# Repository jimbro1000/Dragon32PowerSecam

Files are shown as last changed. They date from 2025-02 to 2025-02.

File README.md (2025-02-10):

# SECAM Dragon 32 Power Board

This project is a historic record of the Dragon 32 SECAM power board.
Part Number 41504. This is not intended for fabrication but should be
dimensionally correct.

The board is unique in that it contains a full YPrPb conversion to
RGB - something very lacking from the original design

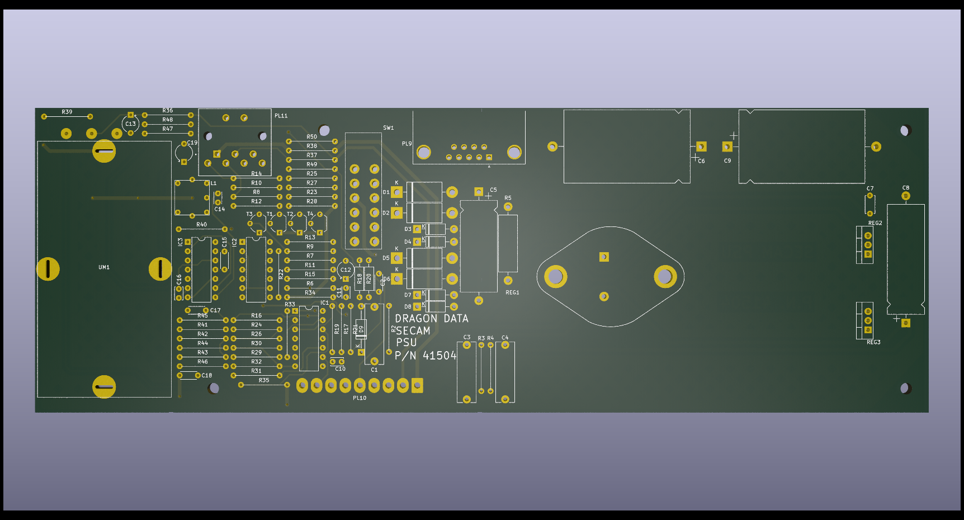
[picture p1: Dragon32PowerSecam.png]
Render of pcb top


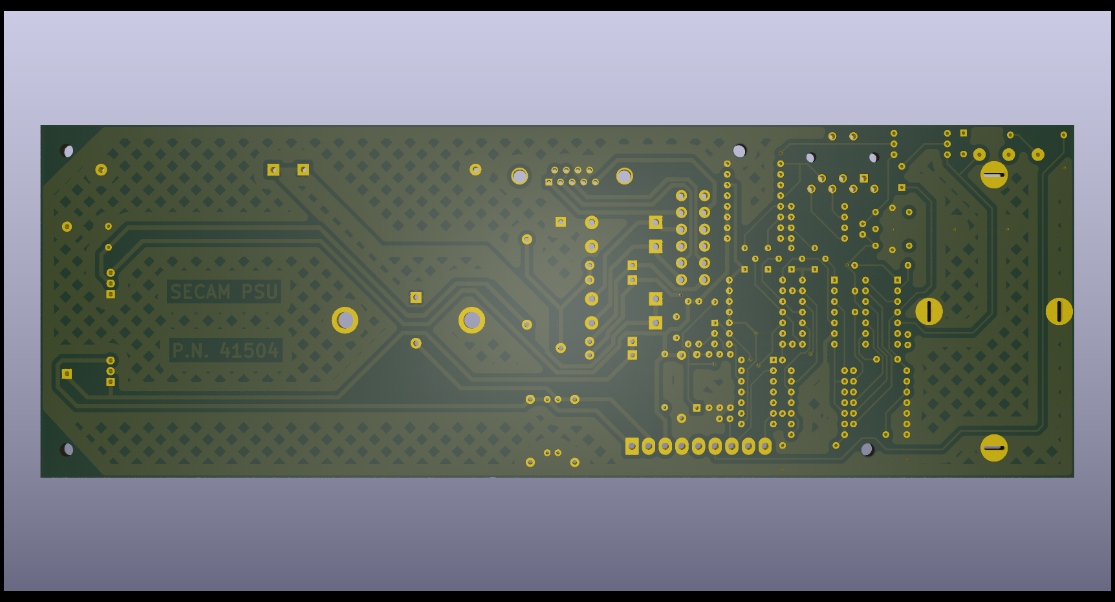
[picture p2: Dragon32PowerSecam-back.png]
Render of pcb bottom


## Compatibility

This board can only be used with a SECAM version of the main CPU
board, see https://github.com/jimbro1000/Dragon32Issue2aSecam

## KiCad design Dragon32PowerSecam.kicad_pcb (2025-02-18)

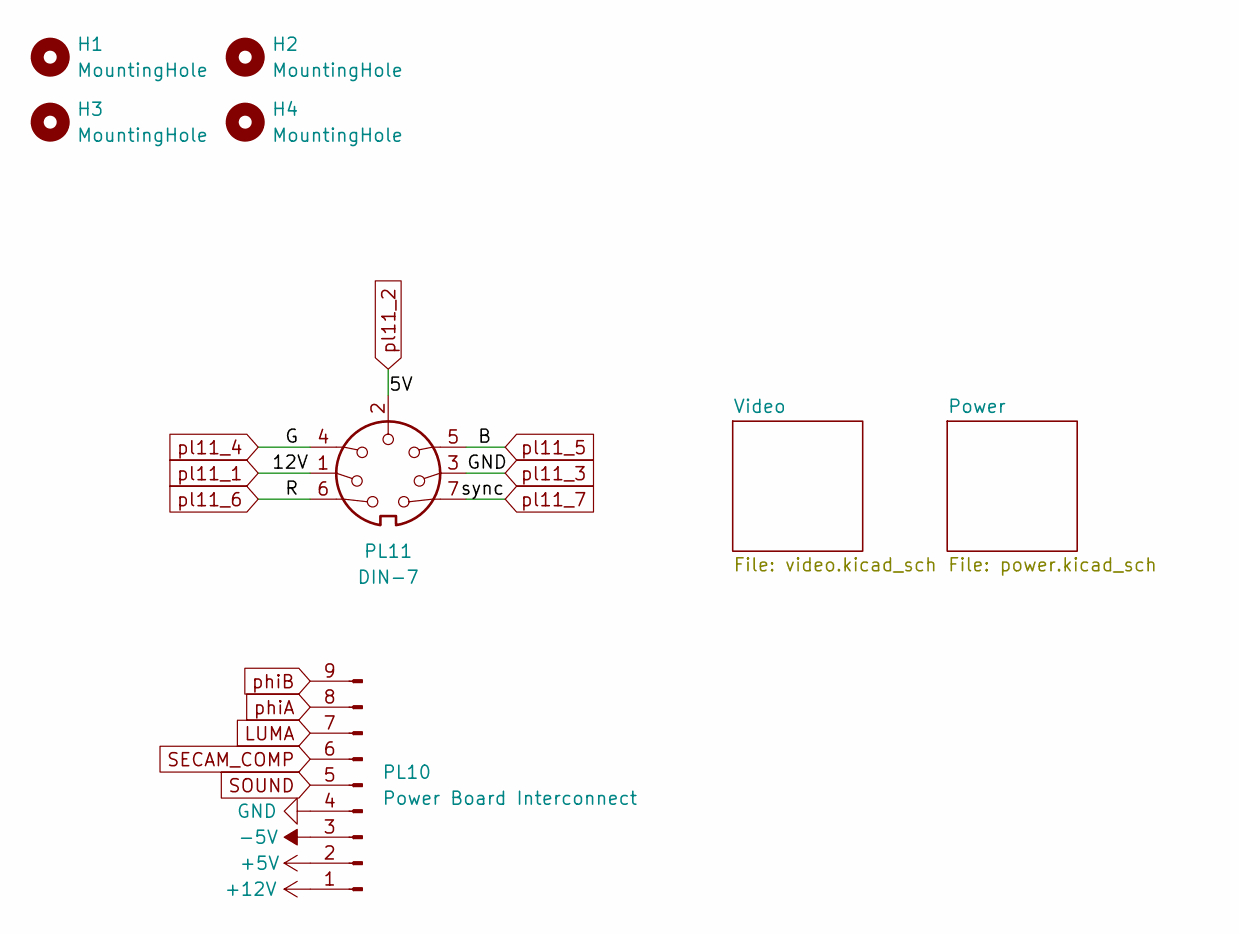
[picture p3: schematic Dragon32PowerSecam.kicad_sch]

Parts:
H1, H2, H3, H4: MountingHole; MountingHole_3.2mm_M3
PL10: Power Board Interconnect; Molex_KK-396_A-41791-0009_1x09_P3.96mm_Vertical; DigiKey 2057-LHD-09-TS-ND
PL11: DIN-7; CUI_SDS-70J; DigiKey CP-2370-ND

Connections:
+5V: PL10.2; also elsewhere on the board
+12V: PL10.1; also elsewhere on the board
-5V: PL10.3; also elsewhere on the board
LUMA: PL10.7; also elsewhere on the board
SECAM_COMP: PL10.6; also elsewhere on the board
SOUND: PL10.5; also elsewhere on the board
phiA: PL10.8; also elsewhere on the board
phiB: PL10.9; also elsewhere on the board
pl11_1: PL11.1; also elsewhere on the board
pl11_2: PL11.2; also elsewhere on the board
pl11_3: PL10.4, PL11.3; also elsewhere on the board
pl11_4: PL11.4; also elsewhere on the board
pl11_5: PL11.5; also elsewhere on the board
pl11_6: PL11.6; also elsewhere on the board
pl11_7: PL11.7; also elsewhere on the board

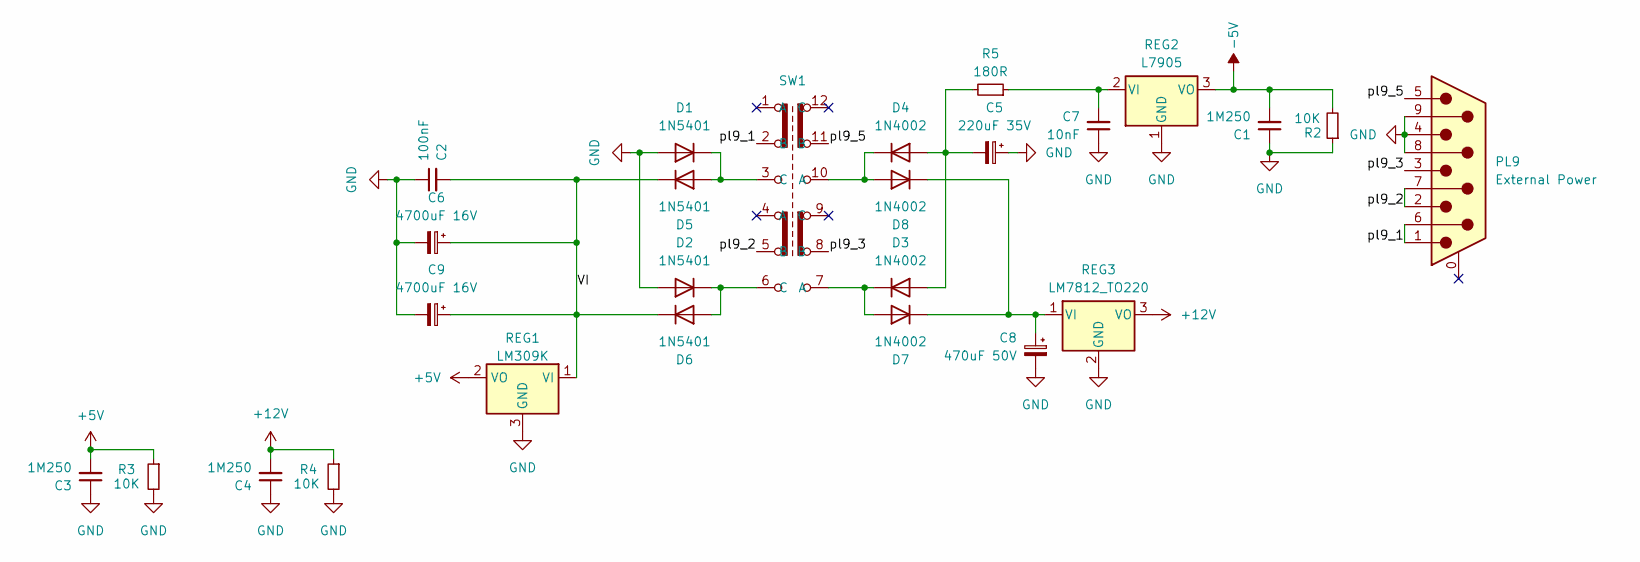
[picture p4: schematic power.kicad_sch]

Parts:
C1, C3, C4: 1M250; C_Rect_L16.5mm_W5.0mm_P15.00mm_MKT
C2: 100nF; C_Disc_D4.3mm_W1.9mm_P5.00mm
C5: 220uF 35V; CP_Axial_L25.0mm_D10.0mm_P30.00mm_Horizontal
C6, C9: 4700uF 16V; CP_Axial_L34.5mm_D20.0mm_P41.00mm_Horizontal
C7: 10nF; C_Disc_D4.7mm_W2.5mm_P5.00mm
C8: 470uF 50V; CP_Axial_L30.0mm_D10.0mm_P35.00mm_Horizontal
D1, D2, D5, D6: 1N5401; D_DO-201AD_P15.24mm_Horizontal
D3, D4, D7, D8: 1N4002; D_DO-41_SOD81_P10.16mm_Horizontal
PL9: External Power; DSUB-9_Male_Horizontal_P2.77x2.84mm_EdgePinOffset9.90mm_Hou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
R2, R3, R4: 10K; R_Axial_DIN0309_L9.0mm_D2.5mm_P12.70mm_Horizontal
R5: 180R; R_Axial_DIN0516_L15.5mm_D5.0mm_P20.32mm_Horizontal
REG1: LM309K; TO-3
REG2: L7905; TO-220-3_Vertical
REG3: LM7812_TO220; TO-220-3_Vertical
SW1: Switch_Push_Interlock_4P2T

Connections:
+5V: C3.2, R3.1, REG1.2 (VO); also elsewhere on the board
+12V: C4.2, R4.1, REG3.3 (VO); also elsewhere on the board
-5V: C1.2, R2.2, REG2.3 (VO); also elsewhere on the board
/Power/VI: C2.2, C6.1, C9.1, D5.1 (K), D6.1 (K), REG1.1 (VI)
/Power/pl9_1: PL9.1, PL9.6, SW1.2 (B)
/Power/pl9_2: PL9.2, PL9.7, SW1.5 (B)
/Power/pl9_3: PL9.3, SW1.8 (B)
/Power/pl9_5: PL9.5, SW1.11 (B)
unnamed: D1.1 (K), D5.2 (A), SW1.3 (C)
unnamed: D2.1 (K), D6.2 (A), SW1.6 (C)
unnamed: C5.2, D3.2 (A), D4.2 (A), R5.2
unnamed: D3.1 (K), D7.2 (A), SW1.7 (A)
unnamed: D4.1 (K), D8.2 (A), SW1.10 (A)
unnamed: C8.1, D7.1 (K), D8.1 (K), REG3.1 (VI)
unnamed: C7.2, R5.1, REG2.2 (VI)
pl11_3: C1.1, C2.1, C3.1, C4.1, C5.1, C6.2, C7.1, C8.2, C9.2, D1.2 (A), D2.2 (A), PL9.4, PL9.8, PL9.9, R2.1, R3.2, R4.2, REG1.3 (GND), REG2.1 (GND), REG3.2 (GND); also elsewhere on the board

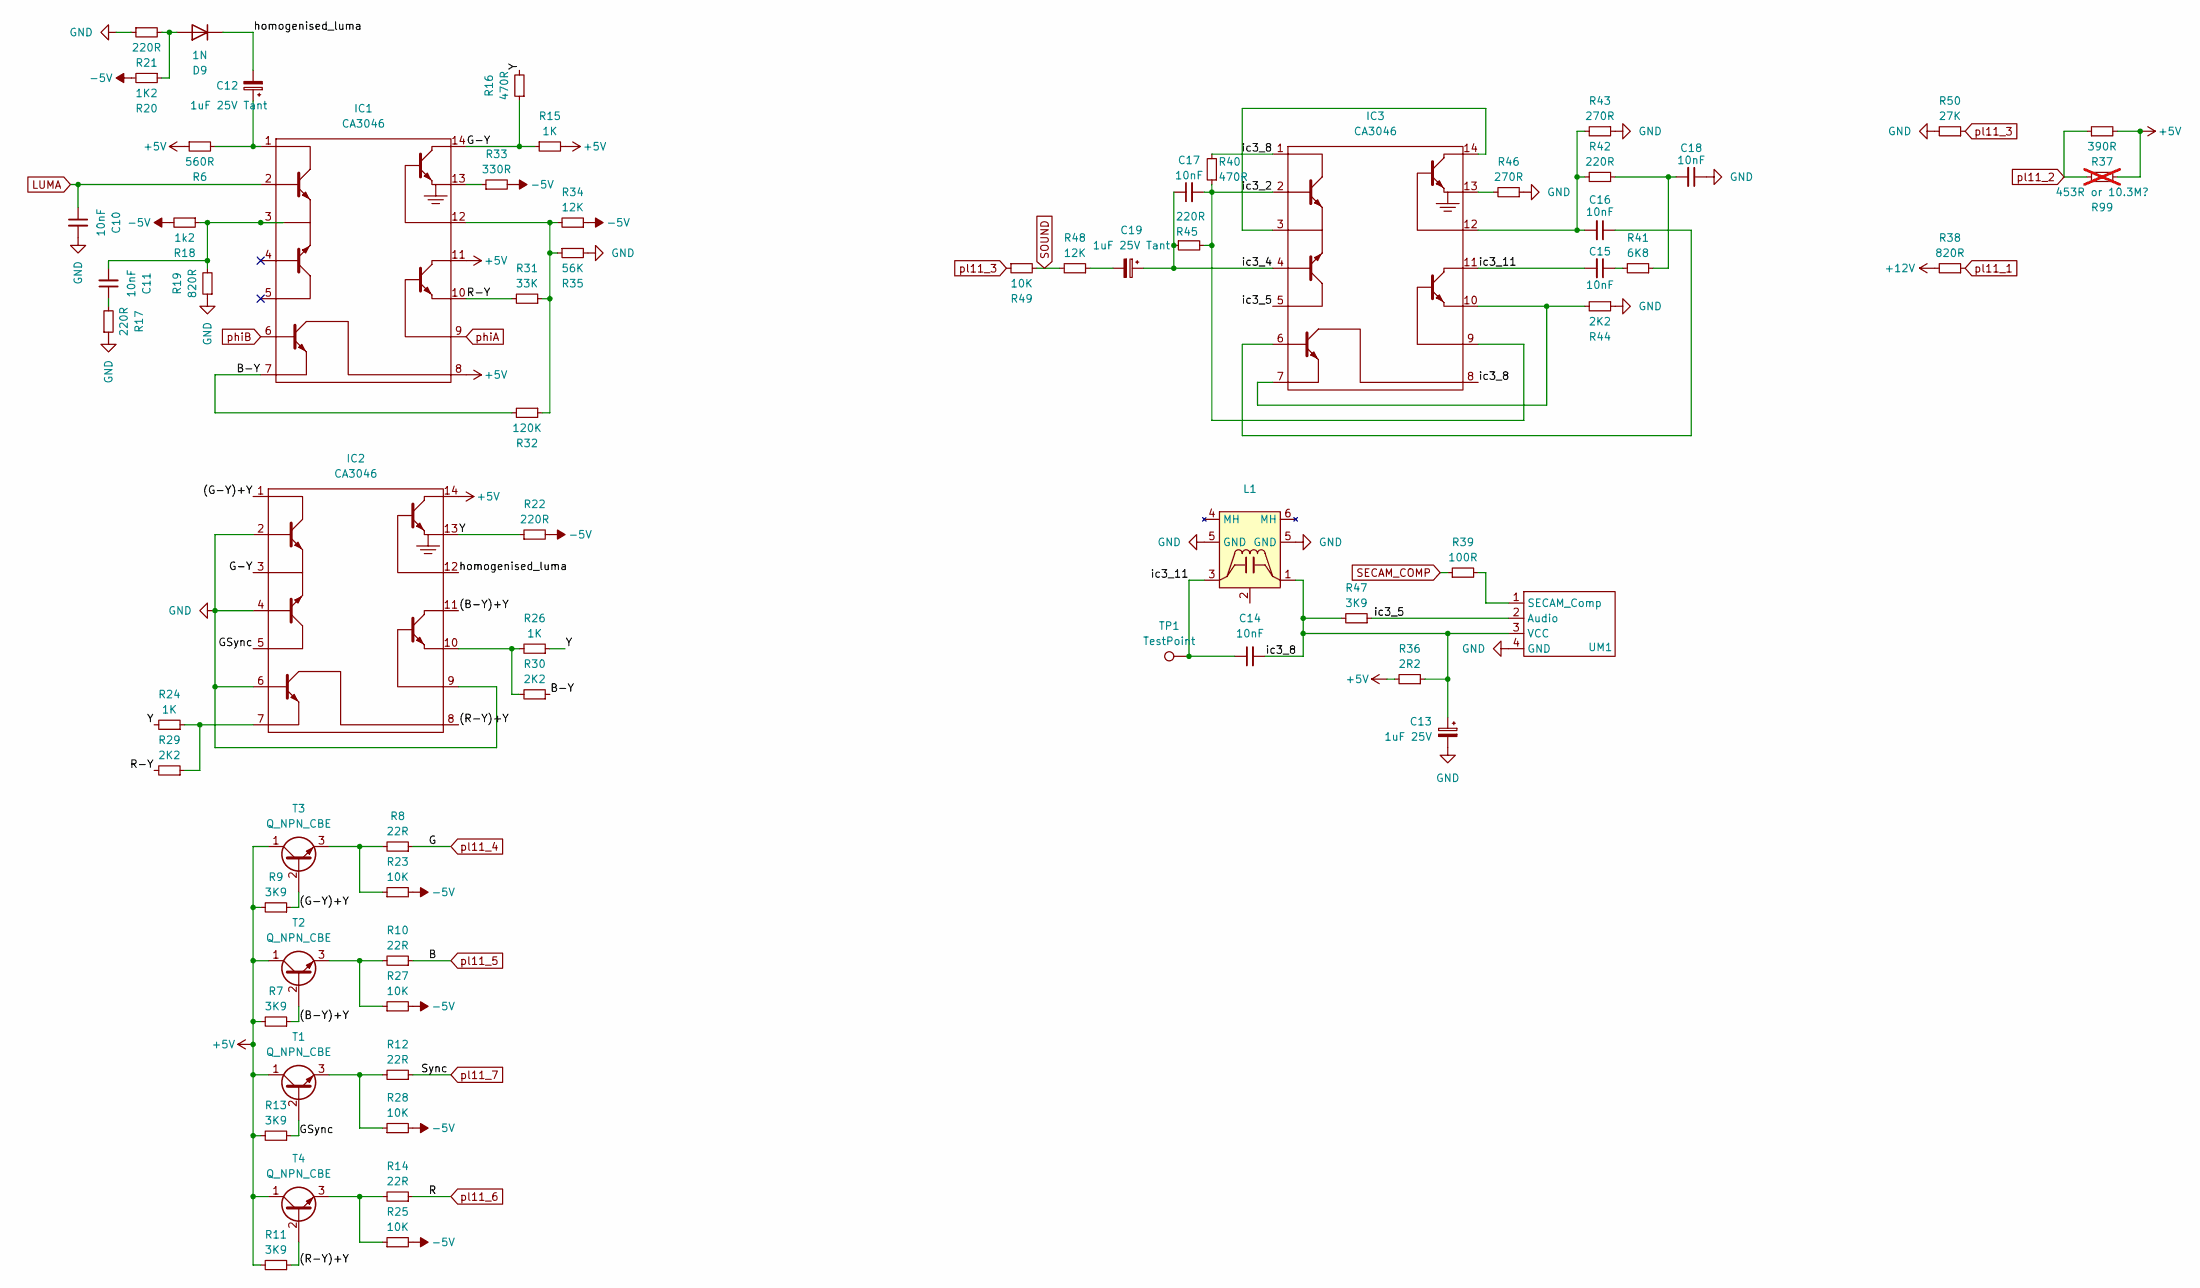
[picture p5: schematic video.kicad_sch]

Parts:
C10, C16: 10nF; C_Disc_D3.4mm_W2.1mm_P2.50mm
C11, C14: 10nF; C_Disc_D3.0mm_W2.0mm_P2.50mm
C12, C19: 1uF 25V Tant; CP_Radial_Tantal_D4.5mm_P5.00mm
C13: 1uF 25V; CP_Radial_Tantal_D4.5mm_P5.00mm
C15, C17, C18: 10nF; C_Disc_D4.3mm_W1.9mm_P5.00mm
D9: 1N; D_A-405_P12.70mm_Horizontal
IC1, IC2, IC3: CA3046; DIP-14_W7.62mm
L1: TOKO_RCL_10K
R6: 560R; R_Axial_DIN0309_L9.0mm_D2.5mm_P12.70mm_Horizontal
R7, R9, R11, R13, R47: 3K9; R_Axial_DIN0309_L9.0mm_D2.5mm_P12.70mm_Horizontal
R8, R10, R12, R14: 22R; R_Axial_DIN0309_L9.0mm_D2.5mm_P12.70mm_Horizontal
R15, R24, R26: 1K; R_Axial_DIN0309_L9.0mm_D2.5mm_P12.70mm_Horizontal
R16, R40: 470R; R_Axial_DIN0309_L9.0mm_D2.5mm_P12.70mm_Horizontal
R17, R21, R22, R42, R45: 220R; R_Axial_DIN0309_L9.0mm_D2.5mm_P12.70mm_Horizontal
R18: 1k2; R_Axial_DIN0207_L6.3mm_D2.5mm_P10.16mm_Horizontal
R19, R38: 820R; R_Axial_DIN0309_L9.0mm_D2.5mm_P12.70mm_Horizontal
R20: 1K2; R_Axial_DIN0207_L6.3mm_D2.5mm_P10.16mm_Horizontal
R23, R25, R27, R28, R49: 10K; R_Axial_DIN0309_L9.0mm_D2.5mm_P12.70mm_Horizontal
R29, R30, R44: 2K2; R_Axial_DIN0309_L9.0mm_D2.5mm_P12.70mm_Horizontal
R31: 33K; R_Axial_DIN0309_L9.0mm_D2.5mm_P12.70mm_Horizontal
R32: 120K; R_Axial_DIN0309_L9.0mm_D2.5mm_P12.70mm_Horizontal
R33: 330R; R_Axial_DIN0309_L9.0mm_D2.5mm_P12.70mm_Horizontal
R34, R48: 12K; R_Axial_DIN0309_L9.0mm_D2.5mm_P12.70mm_Horizontal
R35: 56K; R_Axial_DIN0309_L9.0mm_D2.5mm_P12.70mm_Horizontal
R36: 2R2; R_Axial_DIN0309_L9.0mm_D2.5mm_P12.70mm_Horizontal
R37: 390R; R_Axial_DIN0309_L9.0mm_D2.5mm_P12.70mm_Horizontal
R39: 100R; R_Axial_DIN0309_L9.0mm_D2.5mm_P12.70mm_Horizontal
R41: 6K8; R_Axial_DIN0309_L9.0mm_D2.5mm_P12.70mm_Horizontal
R43, R46: 270R; R_Axial_DIN0309_L9.0mm_D2.5mm_P12.70mm_Horizontal
R50: 27K; R_Axial_DIN0309_L9.0mm_D2.5mm_P12.70mm_Horizontal
R99: 453R or 10.3M?; R_Axial_DIN0309_L9.0mm_D2.5mm_P12.70mm_Horizontal; not fitted
T1, T2, T3, T4: Q_NPN_CBE; TO-92_Wide
TP1: TestPoint; TestPoint_THTPad_D1.0mm_Drill0.5mm
UM1: RF_Modulator_Astec_UM1601

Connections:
+5V: IC1.8, IC1.11, IC2.14, R6.1, R7.2, R9.2, R11.2, R13.2, R15.2, R36.2, R37.2, R99.2, T1.1 (C), T2.1 (C), T3.1 (C), T4.1 (C); also elsewhere on the board
+12V: R38.2; also elsewhere on the board
-5V: R18.2, R20.2, R22.2, R23.2, R25.2, R27.2, R28.2, R33.2, R34.1; also elsewhere on the board
/Video/(B-Y)+Y: IC2.11, R7.1, T2.2 (B)
/Video/(G-Y)+Y: IC2.1, R9.1, T3.2 (B)
/Video/(R-Y)+Y: IC2.8, R11.1, T4.2 (B)
/Video/B-Y: IC1.7, R30.1, R32.2
/Video/G-Y: IC1.14, IC2.3, R15.1, R16.1
/Video/GSync: IC2.5, R13.1, T1.2 (B)
/Video/R-Y: IC1.10, R29.2, R31.2
/Video/Y: IC2.13, R16.2, R22.1, R24.2, R26.1
/Video/homogenised_luma: C12.2, D9.1 (K), IC2.12
/Video/ic3_2: C17.2, IC3.2, IC3.9, R40.1, R45.2
/Video/ic3_4: C17.1, C19.1, IC3.4, R45.1
/Video/ic3_5: IC3.5, R47.1, UM1.2 (Audio)
/Video/ic3_8: C13.1, C14.2, IC3.1, IC3.8, L1.1, R36.1, R40.2, R47.2, UM1.3 (VCC)
/Video/ic3_11: C14.1, C15.2, IC3.11, L1.3, TP1.1
LUMA: C10.1, IC1.2; also elsewhere on the board
unnamed: C11.1, R17.2
unnamed: C11.2, IC1.3, R18.1, R19.2
unnamed: C12.1, IC1.1, R6.2
unnamed: C15.1, R41.2
unnamed: C16.1, IC3.6
unnamed: C16.2, IC3.12, R42.2, R43.2
unnamed: C18.2, R41.1, R42.1
unnamed: C19.2, R48.1
unnamed: D9.2 (A), R20.1, R21.2
unnamed: IC1.12, R31.1, R32.1, R34.2, R35.1
unnamed: IC1.13, R33.1
unnamed: IC2.7, R24.1, R29.1
unnamed: IC2.10, R26.2, R30.2
unnamed: IC3.7, IC3.10, R44.2
unnamed: IC3.13, R46.2
unnamed: IC3.3, IC3.14
unnamed: R12.2, R28.1, T1.3 (E)
unnamed: R10.2, R27.1, T2.3 (E)
unnamed: R8.2, R23.1, T3.3 (E)
unnamed: R14.2, R25.1, T4.3 (E)
unnamed: R39.2, UM1.1 (SECAM_Comp)
SECAM_COMP: R39.1; also elsewhere on the board
SOUND: R48.2, R49.2; also elsewhere on the board
phiA: IC1.9; also elsewhere on the board
phiB: IC1.6; also elsewhere on the board
pl11_1: R38.1; also elsewhere on the board
pl11_2: R37.1, R99.1; also elsewhere on the board
pl11_3: C10.2, C13.2, C18.1, IC2.2, IC2.4, IC2.6, IC2.9, L1.5 (GND), R17.1, R19.1, R21.1, R35.2, R43.1, R44.1, R46.1, R49.1, R50.1, R50.2, UM1.4 (GND); also elsewhere on the board
pl11_4: R8.1; also elsewhere on the board
pl11_5: R10.1; also elsewhere on the board
pl11_6: R14.1; also elsewhere on the board
pl11_7: R12.1; also elsewhere on the board

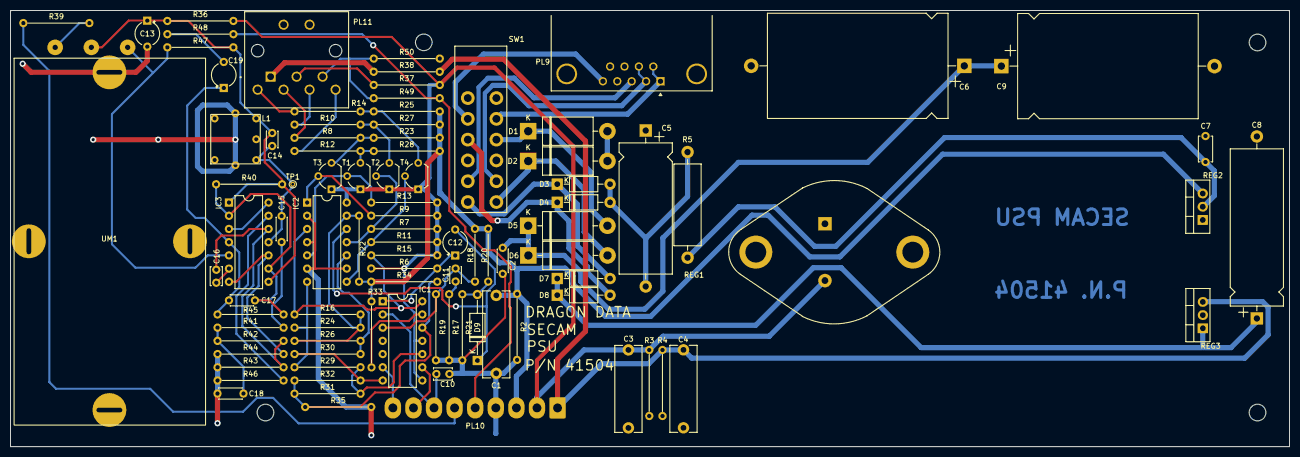
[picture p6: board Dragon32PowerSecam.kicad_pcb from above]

Board: 2 copper layers, 246.0 x 83.9 mm, 98 parts (0 on the bottom side), 62 nets.

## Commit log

2025-02-04 initial layout
    [Dragon32PowerSecam.kicad_pcb, Dragon32PowerSecam.kicad_sch, power.kicad_sch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]
2025-02-04 video tracing
    [Dragon32PowerSecam.kicad_pcb, Dragon32PowerSecam.kicad_sch, video.kicad_sch]
2025-02-07 more video tracing
    [Dragon32PowerSecam.kicad_pcb, Dragon32PowerSecam.kicad_sch, power.kicad_sch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]
2025-02-07 power tracing
    [Dragon32PowerSecam.kicad_pcb, power.kicad_sch, video.kicad_sch]
2025-02-09 layout and routing complete
    [Dragon32PowerSecam.kicad_pcb, power.kicad_sch, video.kicad_sch]
2025-02-09 rationalise video
    [video.kicad_sch]
2025-02-10 rationalise rgb circuit
    [Dragon32PowerSecam.kicad_pcb, Dragon32PowerSecam.kicad_sch, power.kicad_sch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]
2025-02-17 update labelling
    [Dragon32PowerSecam.kicad_pcb, Dragon32PowerSecam.kicad_sch, video.kicad_sch]
2025-02-18 label rf can
    [Dragon32PowerSecam.kicad_pcb, video.kicad_sch]
